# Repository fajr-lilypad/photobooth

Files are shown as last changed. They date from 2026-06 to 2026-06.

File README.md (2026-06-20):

# Mini Photobooth!

A cute photobooth that takes pictures and prints them out for you!



I came up with this project because I thought it would be a good idea to move away from the audio based projects I was doing before and do something more physical. At first, I was thinking a digicam like thing in a tamogatchi syle case, but then I thought it would be cool to have a mini polaroid like photobooth, where people could come in room and take a quick photo! Obviously it won't be the most high quality, but it will be cute nonetheless! This will be a fun but practical accessory that I will definetly be using regularly as someone who is a fan of physical media! Some special things I did for this project include the fact that it is my first electronics project without a pcb, it has friction fit walls that snap together to make a case, and it includes a fidget button that doesnt do anything next to the shutter button (for funsies) along with a shutdown button.

# CAD

## Case

<table>
  <tr>
    <td>
    
    </td>
    <td>
    
    </td>
    <td>
      
    </td>
  </tr>
</table>

Case Notes:
- (right to left) case assembly, case inside view, printer holder
- Case will be printed in several pieces connected with finger joints, in order for easy printing, assembly, charging, and troubleshooting.
- Printer holder will be screwed in with 3/32 screws via holes on bottom piece
- Button holes are socketed from inside for snap fit with Cherry MX keys

## Full Assembly

<table>
   <tr>
      <td>
   
</td>
      <td>
   
      </td>
   </tr>
</table>

<table>
  <tr>
    <td>
    
    </td>
    <td>
      
    </td>
    <td>
      
    </td>
  </tr>
</table>

Assembly Notes:
- Camera Module and Screen are secured using standoffs
- Printer is secured with custom holder screwed onto bottom plate
- Ample space provided for wiring management
- Yellow button on the right only serves only as fidget clicker, heart shaped button is shutter, leftmost button is shutdown button.

# Wiring Diagram


Wiring Notes 

- Screen, Camera, and printer are all connected using hdmi cables
- Diagram shows shutdown button and shutter button
- Shutter Button (Cherry MX Switch):
Pin A: Physical Pin 36 (GPIO 16)
Pin B: Physical Pin 34 (GND)
-Shutdown Button (Optional Switch):
Pin A: Physical Pin 37 (GPIO 26)
Pin B: Physical Pin 39 (GND)

# Zine !!


# Build Guide
1. Assemble the Case: Print out each wall and put together through finger joints, the friction fit will keep them together.
2. Mount the printer holder with 3/32 screws on the bottom plate and slide the printer in with a fresh roll. Feed a bit of paper through the slot in the front wall.
3. Wire the buttons according to the diagram, and place them in the socketed holes.
4. Mount the camera module and screen (with raspberry pi attatched) to the inside of the front wall with 3/32 screws.
5. Plug in hdmi cables for screen and printer, upload code and test shutter and shutdown button.
6. Enjoy! To use, press heartshaped button and wait for an instant pic!

## Acknowledgements:
- Thank you to the fallout team and hackclub for making this project possible!
- Thank you to digiiash for helping with code!

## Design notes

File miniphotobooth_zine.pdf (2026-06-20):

# mini photobooth

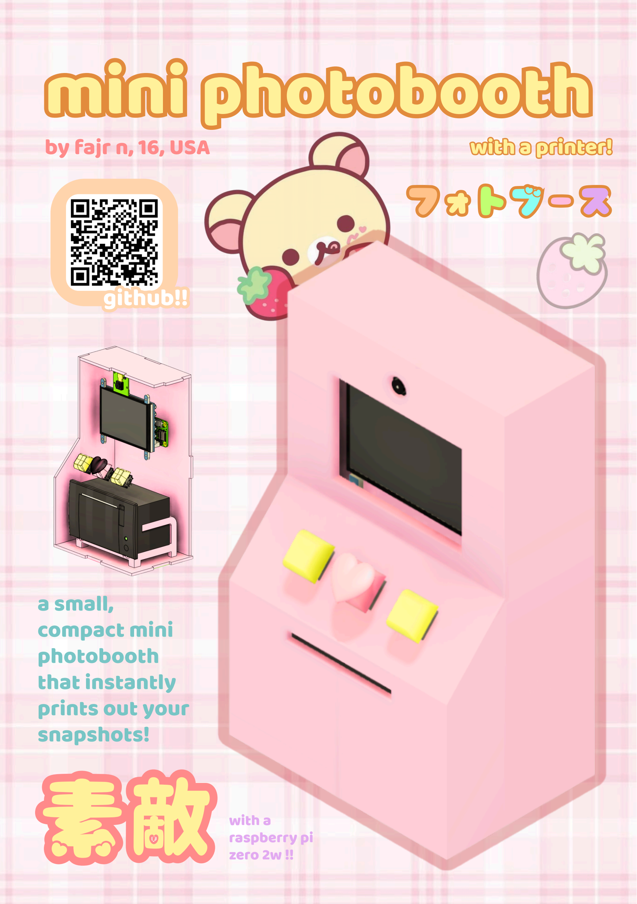
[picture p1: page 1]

フォトブース

by fajr n, 16, USA | wwiitthh aa pprriinntteerr!!

a small,
compact mini
photobooth
that instantly
prints out your
snapshots!
素敵

ggiitthhuubb!!!!

with a
raspberry pi
zero 2w !!

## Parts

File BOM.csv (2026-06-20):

Item | Purpose | # | Cost | Supplier | Link
Raspberry Pi Camera Module | Camera | 1 | $10.03 | Aliexpress | https://www.aliexpress.us/item/3256809071934284.html?src=google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
USB 58mm Mini Embedded Thermal Printer | Printer | 1 | $24.03 | Aliexpress | https://www.aliexpress.us/item/3256809438791938.html?scm_id=1007.40050.354490.0&scm-url=1007.40050.354490.0
Raspberry Pi Zero 2W | Microcontroller | 1 | $19.05 | Adafruit | https://www.adafruit.com/product/5291
Raspberry Pi Zero Camera Cable | Camera Cable | 1 | $1.27 | Aliexpress | https://www.aliexpress.us/item/3256809503403005.html?curPageLogUid=9xxca3IriSpF
Micro-USB to USB-A | Adapter | 1 | $3.99 | Microcenter | https://www.microcenter.com/product/624026/inland-micro-usb-(type-b)-male-to-usb-20-(type-a)-female-slim-otg-adaptor-for-smartphone-or-tablet-6-in-black
16GB Micro SD Card | SD Card | 1 | $4.71 | Aliexpress | https://www.aliexpress.us/item/2251832813194768.html?scm_id=1007.40050.354490.0&scm-url=1007.40050.354490.0
5V 3A Raspberry Pi Power Supply | Charging | 1 | $3.89 | Aliexpress | https://www.aliexpress.us/item/2251832620044216.html?src=google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
3.5 Inch Mini HDMI Monitor LCD Screen 480*320 | Screen | 1 | $25.48 | Aliexpress | https://www.aliexpress.us/item/3256803762052188.html?curPageLogUid=MvIJ7yAstgl0
Cherry MX Switch | Shutter Button | 1 | Owned (OG Price $3.19) | Aliexpress | https://www.aliexpress.us/item/3256805881801670.html?curPageLogUid=bUxzhrcXxo5S
3/32 Self Tapping Plastic Screws | Screw | 1 | $0.92 | Aliexpress | https://www.aliexpress.us/item/3256807955659503.html?src=google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
 |  | Subtotal | $98.06

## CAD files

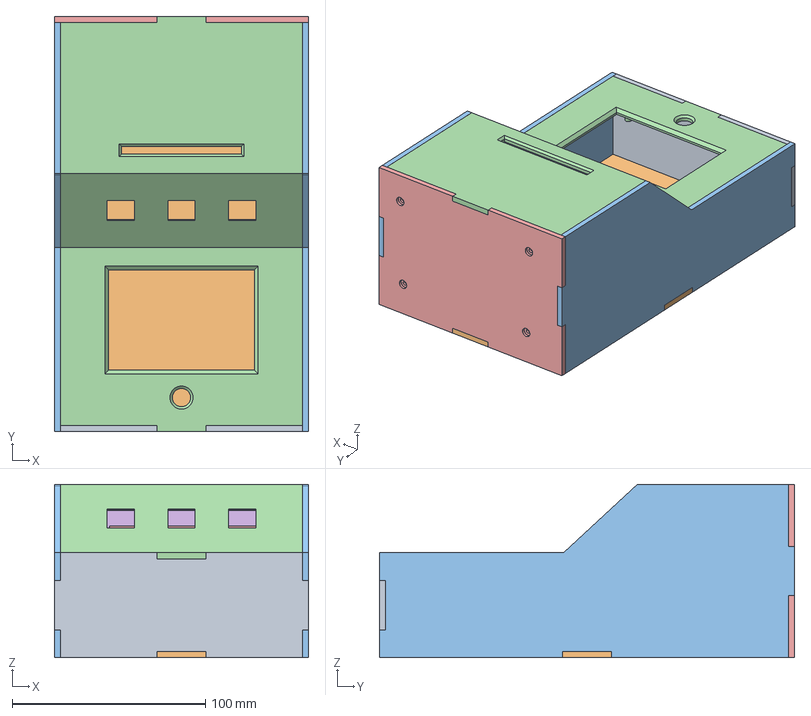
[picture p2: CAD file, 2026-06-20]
CAD/Case/Photobooth Case Assembly.step
131.5 x 214.6 x 89.6 mm

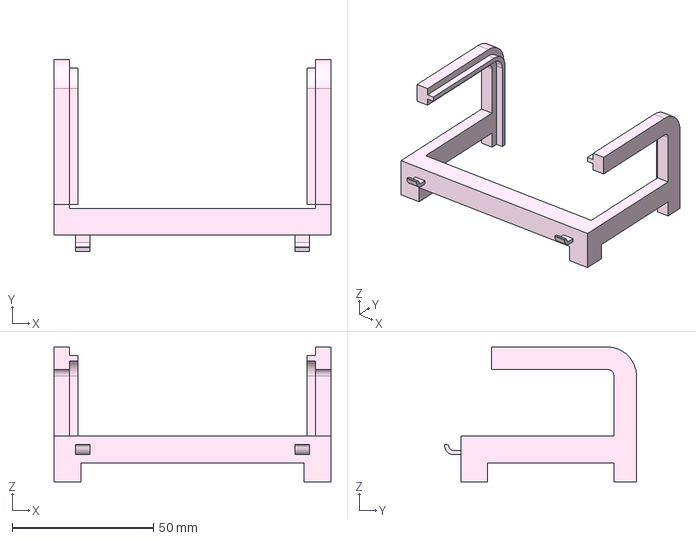
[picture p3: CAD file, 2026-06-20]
CAD/Case/Printer Holder.step
98.0 x 68.0 x 47.8 mm

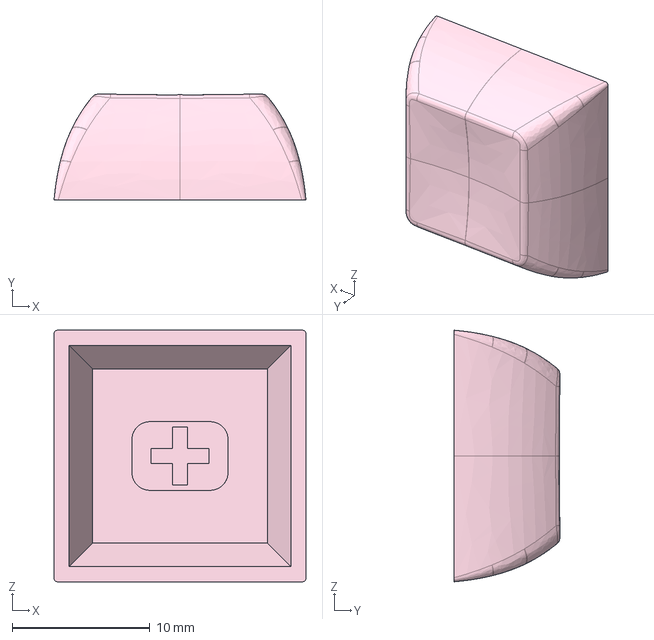
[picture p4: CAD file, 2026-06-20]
CAD/Electronics/custom keycap.step
18.3 x 7.69 x 18.3 mm

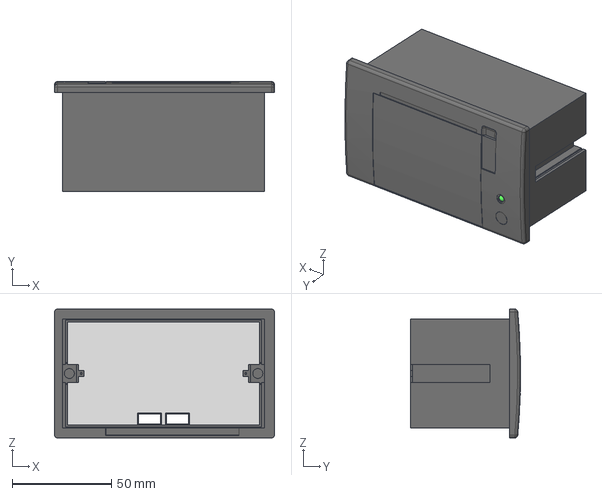
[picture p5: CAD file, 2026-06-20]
CAD/Electronics/thermal_printer .step
111.0 x 55.5 x 65.0 mm

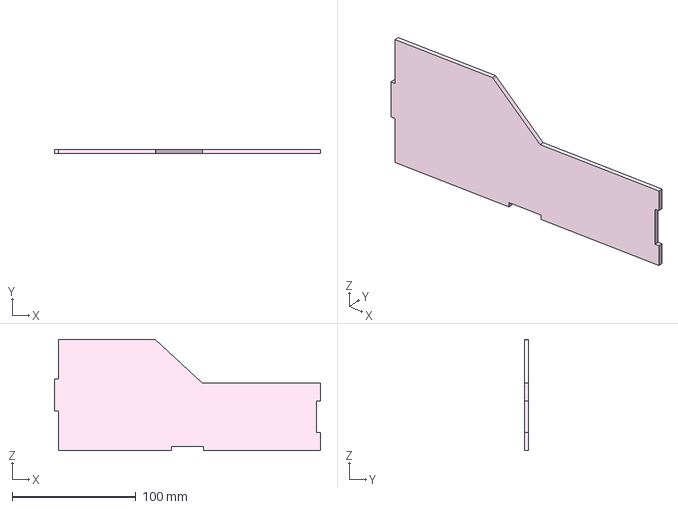
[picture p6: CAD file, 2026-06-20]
CAD/Case/Side Wall.step
214.6 x 3.17 x 89.6 mm

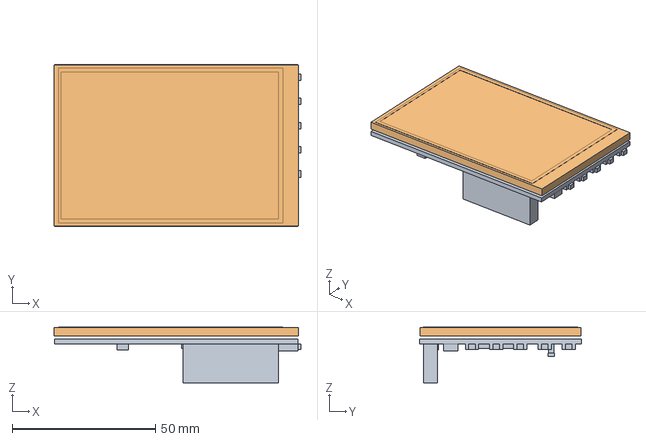
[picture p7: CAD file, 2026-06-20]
CAD/Electronics/Waveshare_HDMI_3,5_Zoll_Display.stp
86.2 x 56.4 x 19.5 mm

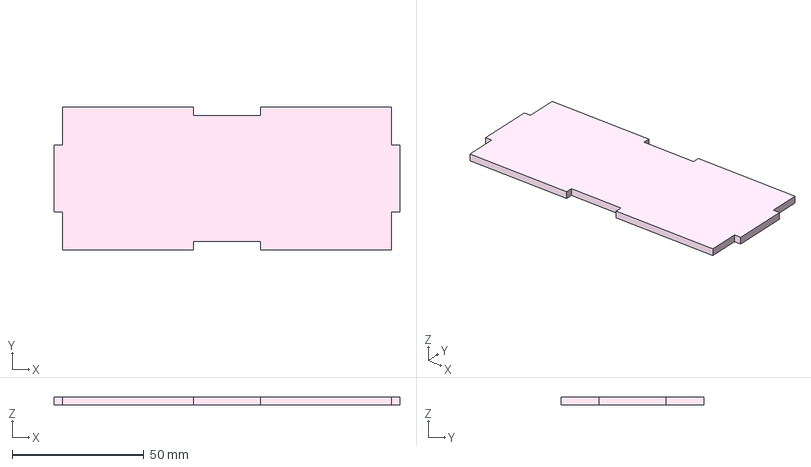
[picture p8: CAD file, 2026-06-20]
CAD/Case/Case Top.step
131.5 x 54.3 x 3.17 mm

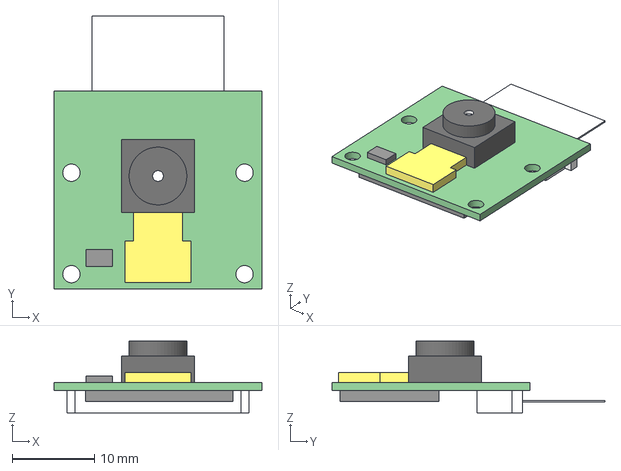
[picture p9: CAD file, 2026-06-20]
CAD/Electronics/RPi cam module.step
25.2 x 33.1 x 8.70 mm

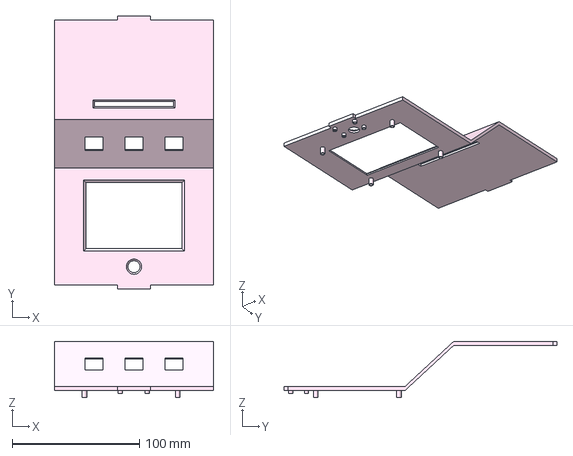
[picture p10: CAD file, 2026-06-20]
CAD/Case/Case Front.step
125.2 x 214.6 x 44.0 mm

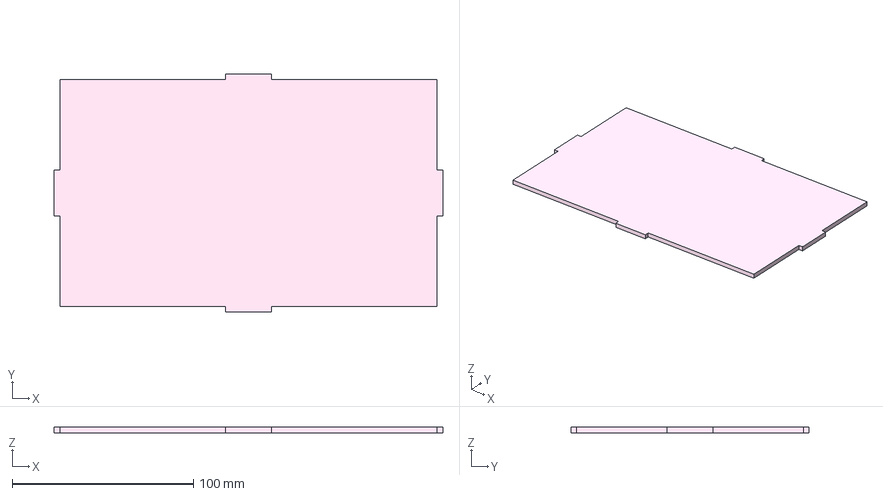
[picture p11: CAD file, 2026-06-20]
CAD/Case/Back Wall.step
214.6 x 131.5 x 3.17 mm

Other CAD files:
CAD/Electronics/DSA_Keycap_CherryMX.step
CAD/Electronics/Cherry_mx .STEP

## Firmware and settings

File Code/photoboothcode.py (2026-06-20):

#!/usr/bin/env python3


import os
import time
import subprocess
import pygame
import RPi.GPIO as GPIO

__author__ = "digiiash"
__license__ = "MIT"
__version__ = "1.0.0"

# ── Configuration ──────────────────────────────────────────────────────────────
SHUTTER_PIN    = 16      # GPIO pin for shutter button (active LOW, BCM numbering)
SHUTDOWN_PIN   = 26      # GPIO pin for shutdown button (active LOW, BCM numbering)
COUNTDOWN_SECS = 3       # how many seconds to count down
COUNTDOWN_HOLD = 1.0     # seconds to display each number
CAPTURE_MS     = 500     # raspistill final-capture timeout in ms
PRINT_CMD      = "raspistill -ex auto --timeout {ms} -o - | lp"

SCRIPT_DIR = os.path.dirname(os.path.abspath(__file__))
IMAGES = {
    "attract":  os.path.join(SCRIPT_DIR, "images", "attract.jpg"),
    "printing": os.path.join(SCRIPT_DIR, "images", "printing.jpg"),
}

# ── Countdown overlay style ────────────────────────────────────────────────────
FONT_SIZE      = 280
NUMBER_COLOR   = (255, 255, 255)  # white number
NUMBER_ALPHA   = 210              # 0-255; 255 = fully opaque
SHADOW_COLOR   = (0, 0, 0)
SHADOW_ALPHA   = 130
SHADOW_OFFSET  = 8                # drop-shadow offset in pixels
CIRCLE_COLOR   = (0, 0, 0)
CIRCLE_ALPHA   = 110              # dim backing circle behind number
CIRCLE_RADIUS  = 160
# ──────────────────────────────────────────────────────────────────────────────


def load_images(screen_size):
    """Load and scale JPEGs; generate a placeholder if a file is missing."""
    loaded = {}
    for key, path in IMAGES.items():
        if not os.path.exists(path):
            print(f"[WARNING] Missing image: {path}")
            surf = pygame.Surface(screen_size)
            surf.fill((20, 20, 20))
            font = pygame.font.SysFont(None, 64)
            label = font.render(f"[{key}]", True, (180, 180, 180))
            surf.blit(label, label.get_rect(center=(screen_size[0] // 2, screen_size[1] // 2)))
            loaded[key] = surf
        else:
            img = pygame.image.load(path).convert()
            loaded[key] = pygame.transform.scale(img, screen_size)
    return loaded


def show(screen, images, key):
    """Blit a full-screen image and flip the display."""
    screen.blit(images[key], (0, 0))
    pygame.display.flip()


def start_preview(screen_w, screen_h):
    """
    Launch raspistill with a full-screen preview window.
    The Pi's GPU composites the camera feed *beneath* the framebuffer layer,
    so wherever pygame paints black (or nothing), the camera shows through.
    """
    preview_rect = f"0,0,{screen_w},{screen_h}"
    proc = subprocess.Popen([
        "raspistill",
        "-ex", "auto",
        "-p", preview_rect,   # position + size of the preview on screen
        "--timeout", "0",     # run until we kill it
    ])
    return proc


def stop_preview(proc):
    """Terminate the preview subprocess, killing it if it doesn't exit cleanly."""
    if proc and proc.poll() is None:
        proc.terminate()
        try:
            proc.wait(timeout=2)
        except subprocess.TimeoutExpired:
            proc.kill()


def draw_countdown_number(screen, number, screen_size, font_large):
    """
    Paint the screen black (camera shows through) then draw:
      - a semi-transparent dark circle as a backing shape
      - a drop shadow
      - the countdown number with partial transparency
    """
    w, h = screen_size
    cx, cy = w // 2, h // 2

    # Black background — the GPU camera layer beneath will show through
    screen.fill((0, 0, 0))

    # Semi-transparent backing circle
    circle_surf = pygame.Surface((CIRCLE_RADIUS * 2, CIRCLE_RADIUS * 2), pygame.SRCALPHA)
    pygame.draw.circle(
        circle_surf,
        (*CIRCLE_COLOR, CIRCLE_ALPHA),
        (CIRCLE_RADIUS, CIRCLE_RADIUS),
        CIRCLE_RADIUS,
    )
    screen.blit(circle_surf, (cx - CIRCLE_RADIUS, cy - CIRCLE_RADIUS))

    # Drop shadow
    shadow_surf = font_large.render(str(number), True, SHADOW_COLOR)
    shadow_surf.set_alpha(SHADOW_ALPHA)
    screen.blit(shadow_surf, shadow_surf.get_rect(center=(cx + SHADOW_OFFSET, cy + SHADOW_OFFSET)))

    # Number
    num_surf = font_large.render(str(number), True, NUMBER_COLOR)
    num_surf.set_alpha(NUMBER_ALPHA)
    screen.blit(num_surf, num_surf.get_rect(center=(cx, cy)))

    pygame.display.flip()


def countdown_with_preview(screen, screen_size, font_large):
    """
    Start the live preview then tick down 3-2-1 with the overlay.
    Returns the preview subprocess so the caller can stop it before capture.
    """
    preview_proc = start_preview(*screen_size)
    time.sleep(0.4)  # let raspistill start painting before we overlay

    for n in range(COUNTDOWN_SECS, 0, -1):
        draw_countdown_number(screen, n, screen_size, font_large)
        time.sleep(COUNTDOWN_HOLD)

    return preview_proc


def take_and_print(screen, images, preview_proc):
    """Kill the preview, show the printing screen, then snap + spool."""
    stop_preview(preview_proc)
    time.sleep(0.1)
    show(screen, images, "printing")
    subprocess.call(PRINT_CMD.format(ms=CAPTURE_MS), shell=True)


def setup_gpio():
    """Configure shutter and shutdown pins as inputs with pull-ups."""
    GPIO.setmode(GPIO.BCM)
    GPIO.setup(SHUTTER_PIN,  GPIO.IN, pull_up_down=GPIO.PUD_UP)
    GPIO.setup(SHUTDOWN_PIN, GPIO.IN, pull_up_down=GPIO.PUD_UP)


def main():
    setup_gpio()

    os.environ["SDL_FBDEV"] = "/dev/fb0"
    os.environ.setdefault("SDL_VIDEODRIVER", "fbcon")

    pygame.init()
    pygame.mouse.set_visible(False)

    info = pygame.display.Info()
    screen_size = (info.current_w, info.current_h)
    screen = pygame.display.set_mode(screen_size, pygame.FULLSCREEN)

    images     = load_images(screen_size)
    font_large = pygame.font.SysFont(None, FONT_SIZE, bold=True)
    clock      = pygame.time.Clock()

    print("Photobooth ready — waiting for button press.")

    try:
        while True:
            # Keep the event queue drained so the OS doesn't think we're frozen
            for event in pygame.event.get():
                if event.type == pygame.QUIT:
                    raise SystemExit
                if event.type == pygame.KEYDOWN and event.key == pygame.K_ESCAPE:
                    raise SystemExit

            show(screen, images, "attract")

            # ── Shutter button ────────────────────────────────────────────
            if GPIO.input(SHUTTER_PIN) == GPIO.LOW:
                while GPIO.input(SHUTTER_PIN) == GPIO.LOW:
                    time.sleep(0.05)          # wait for physical release

                preview_proc = countdown_with_preview(screen, screen_size, font_large)
                take_and_print(screen, images, preview_proc)
                time.sleep(2)
                print("Photo taken and sent to printer!")

            # ── Shutdown button ───────────────────────────────────────────
            if GPIO.input(SHUTDOWN_PIN) == GPIO.LOW:
                while GPIO.input(SHUTDOWN_PIN) == GPIO.LOW:
                    time.sleep(0.05)
                print("Shutdown triggered.")
                time.sleep(1)
                subprocess.call(["sudo", "shutdown", "now"])

            clock.tick(15)

    except (SystemExit, KeyboardInterrupt):
        print("Exiting.")
    finally:
        GPIO.cleanup()
        pygame.quit()


if __name__ == "__main__":
    main()

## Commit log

2026-06-20 Rename Case Bottom.step to CAD/Case/Case Bottom.step
    [Case Bottom.step]
2026-06-20 Rename Back Wall.step to CAD/Case/Back Wall.step
    [Back Wall.step]
2026-06-20 Rename CAD/MX .STEP to CAD/Electronics/Cherry_mx .STEP
    [Cherry_mx .STEP, MX .STEP]
2026-06-20 Rename RPi cam v1.step to RPi cam module.step
    [RPi cam module.step]
